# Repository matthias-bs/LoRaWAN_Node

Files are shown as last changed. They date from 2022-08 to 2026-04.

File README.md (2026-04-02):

# LoRaWAN_Node

Please refer to my [BresserWeatherSensorLW](https://github.com/matthias-bs/BresserWeatherSensorLW) project for an example application. The hardware has some options for a variety of other uses, however.

## TTN Node Board

### Schematic
Please refer to Fritzing or PDF file for most current version!

ttn_node-20220614-2_sch

### PCB
Please refer to Fritzing or PDF file for most current version!

**Note:**

Actually an antenna should not be placed next to circuitry or metal parts, but the decision was made to place the antenna inside the case to avoid leakage or corrosion problems. The concept works perfectly for me. 

ttn_node_v3_pcb

LoRaWAN_Node-1

LoRaWAN_Node-2

### Connectors/Wiring

#### Internal Wiring
```
                           (1)    Fuse
                      + o--------< F1 >-----< +
              BATT1                             U2 (Charger), "Batt"
                      - o-------------------< -
                                 (2)

                      + >-------------------< +
U2 (Charger), "Load"                            U1 (ESP32_Firebeetle)
                      - >-------------------< -
```
Wires (1) and (2) are only needed if the battery holder does not have PCB pins.

#### Connector Wiring
```
                                
                     Power  2 >------------------< +
     Solar Power In                                   2.1mm DC Jack (U2, Charger)
                       GND  1 >------------------< -

                       GND  1 >----------------< 1  GND
     OneWire Socket    VDD  2 >----------------< 2  3V3   LoRaWAN_Node, J2
                       DQ   3 >----------------< 3  DQ
```

ttn_node_wiring

LoRaWAN_Node-3

LoRaWAN_Node-4

### Assembly Options
1. Do not assemble R42, R43, R44 and R55.
2. Assemble C40, R40 and R41 for battery voltage measurement.
3. Assemble R1 if a one-wire sensor is to be used (and this sensor does not have an internal pull-up).
4. Assemble R2 and R3 for connection of I<sup>2</sup>C devices.
5. No pin header has to be assembled for the charger module. The apparently missing connections on the PCB drawing to the module can be ignored.

### Issues and Workarounds
1. The mounting holes are too small for the selected screws (special form; SHR Z B4,5x7,8)<sup>(1)</sup><br>(Fritzing limitation)<br>Workaround: Drilling with 4.5mm or a little filing.
2. The cutouts at the lower corners of the PCB have to be done manually.<br>(apparently Fritzing does not support PCB cutouts)
3. The footprint for the fuse F1 is too narrow.<br>As a workaround, F1 can be placed instead of connector J6 and a pin header at the actual F1 pads can be used to connect the fuse in series to the battery B+ wire. (see photo)
4. Connection from battery B+ to analog input voltage divider is missing.<br>Workaround: Add a wire from B+ to J5.7 (A3) (see photo - white wire)
5. Optionally: Drill a hole to strap the battery in the holder. (see photo)
6. Please see issue https://github.com/matthias-bs/LoRaWAN_Node/issues/1 regarding J5.1 (A0) usage

(1) The screws on the photo are different ones.

## Main Components
### MCU Board
[DFRobot FireBeetle ESP32 IoT Microcontroller](https://www.dfrobot.com/product-1590.html)

**Note 1:** Assemble R10 and R11 with 0 Ohms resistors (or solder joints...) if you want to monitor VB.

**Note 2:** The USB-serial-converter seems to be quite picky - use a short USB cable and lower bitrate when flashing!

### LoRa Radio Transceiver
[Adafruit RFM95W LoRa Radio Transceiver Breakout](https://www.adafruit.com/product/3072) - **868 MHz Version!**

**Note:** Don't use the transceiver without antenna!

### Antenna
[Delock LoRa 868 MHz Antenna SMA plug 3 dBi omnidirectional](https://www.delock.de/produkt/89769/merkmale.html)

## Solar Battery Charger
[Adafruit Universal USB / DC / Solar Lithium Ion/Polymer charger - bq24074](https://www.adafruit.com/product/4755)

**Note:** "Load Out" voltage can be different from battery voltage in certain conditions - see [Adafruit Universal USB / DC / Solar Lithium Ion/Polymer charger - bq24074 -- Overview](https://learn.adafruit.com/adafruit-bq24074-universal-usb-dc-solar-charger-breakout/overview).

## Solar Panel
[Waveshare Solar Panel (6V 5W)](https://www.waveshare.com/solar-panel-6v-5w.htm)

## Options

* [Adapter for DS3231 RTC Module](RTC_Adapter/RTC_Adapter.md)

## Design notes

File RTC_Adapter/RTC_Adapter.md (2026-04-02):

# Adapter for DS3231 RTC Module (for Raspberry Pi) to LoRaWAN_Node

This adapter allows to connect the [DS3231 RTC Module for Raspberry Pi](https://www.berrybase.de/en/ds3231-real-time-clock-module-for-raspberry-pi) to LoRaWAN_Node.

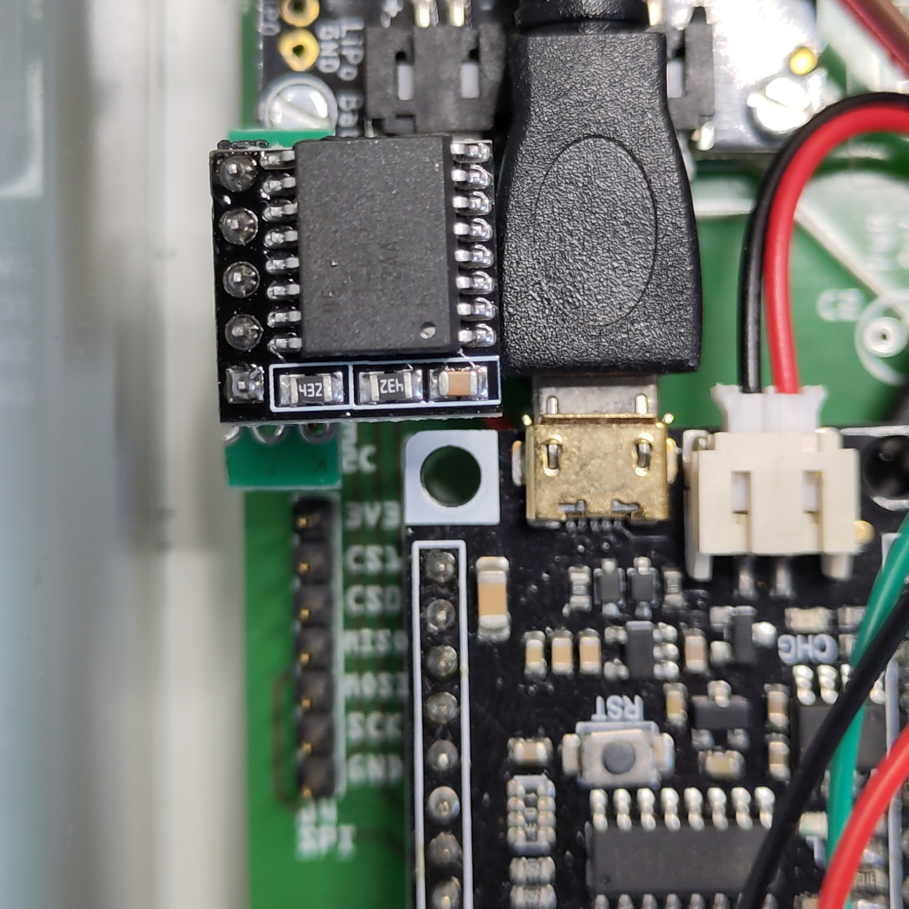
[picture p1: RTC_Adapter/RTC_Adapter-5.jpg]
Mounting Position

                                                                                                                                                                  
The RTC module is connected to the LoRaWAN_Node's connector J3 (I2C Bus).

**Wiring Scheme:**

```ascii
DS3231 Module                  
(Top View; IC)                 
 ┌─────────┐                   
 │ GND   5 ├─────┐ LoRaWAN Node (J3)
 │         │     │  ┌───────┐  
 │ NC    4 │  ┌──┼──┤ 4 3V3 │  
 │         │  │  │  │       │  
 │ SCL   3 ├──┼──┼──┤ 3 SCL │  
 │         │  │  │  │       │  
 │ SDA   2 ├──┼──┼──┤ 2 SDA │  
 │         │  │  │  │       │  
 │ 3V3   1 ├──┘  └──┤ 1 GND │  
 └─────────┘        └───────┘  

```

1. 4-Position Socket Header and Vias for SCL and SDA - Soldering

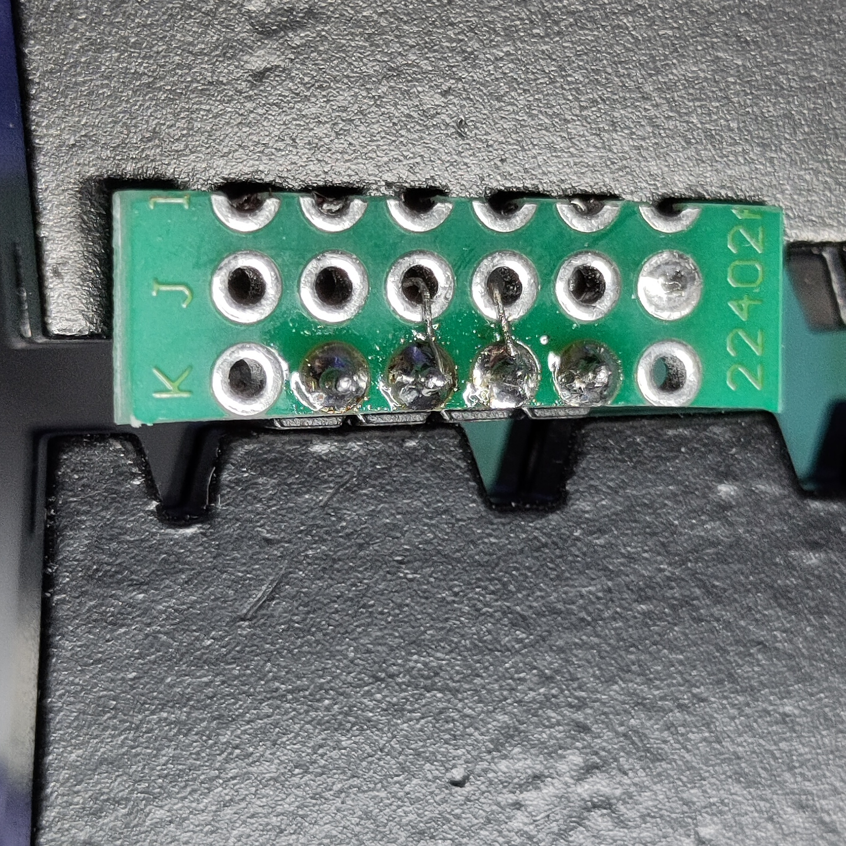
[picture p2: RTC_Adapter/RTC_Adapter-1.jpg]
4-Position Socket Header and Vias - Soldering
   

2. 4-Position Socket Header and Vias for SCL and SDA - Mounting Position

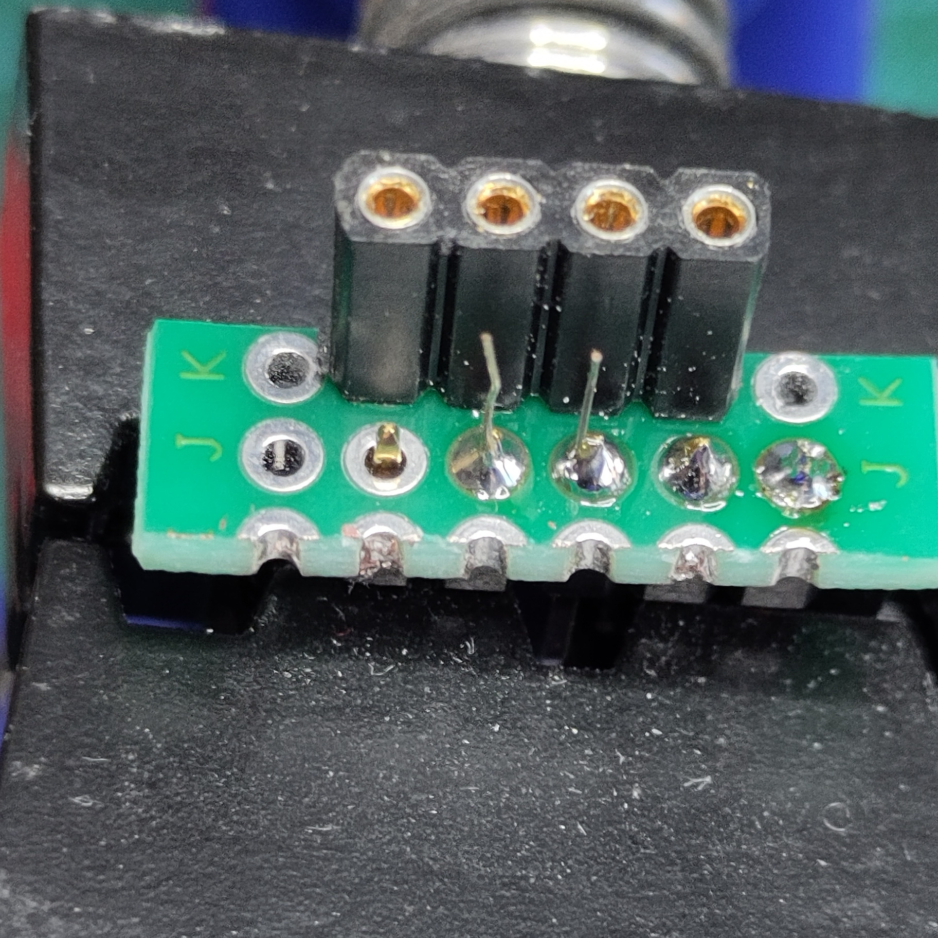
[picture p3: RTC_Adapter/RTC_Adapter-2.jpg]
4-Position Socket Header and Vias - Mounting Position
   

3. 5-Position Pin Header - Mounting Position

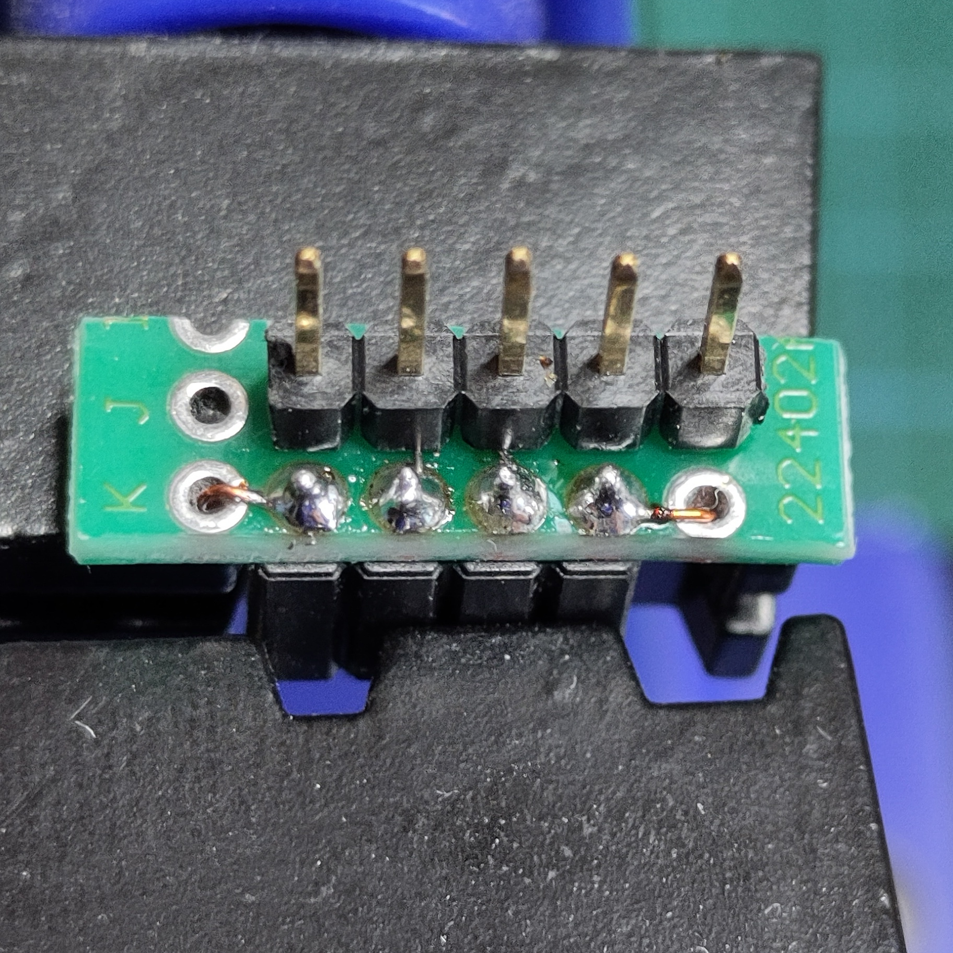
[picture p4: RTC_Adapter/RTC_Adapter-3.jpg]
5-Position Pin Header - Mounting Position
   

4. 5-Position Pin Header - 3V3 and GND Wiring

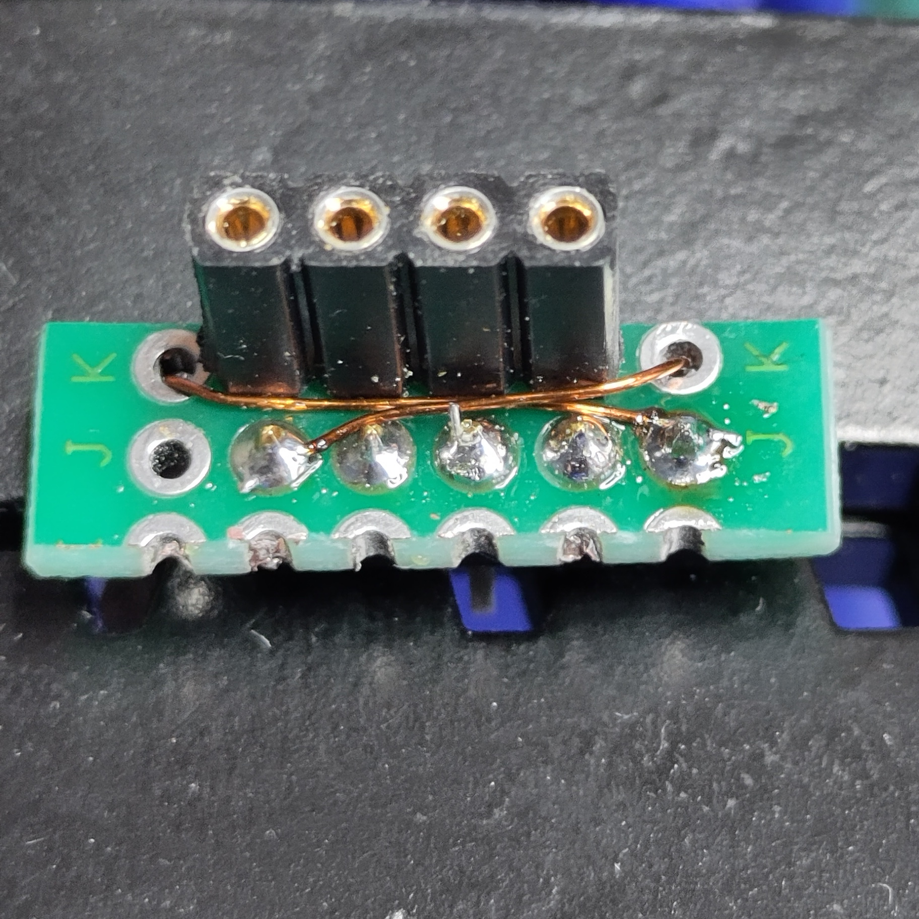
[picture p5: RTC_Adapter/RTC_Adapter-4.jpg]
5-Position Pin Header - 3V3 and GND Wiring


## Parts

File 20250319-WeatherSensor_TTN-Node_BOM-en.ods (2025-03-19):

Pos. | Quantity |  | Unit | Assembly | Part | Part No. | Link
 | min | max
1 | 1 | 1 | Pcs | Sensors | Bresser 5-in-1 Wetterstation |  | https://www.aldi-onlineshop.de/p/5-in-1-wetterstation-1008343/
2 | 1 | 1 | Pcs | Controller | Leiterplatte |  | https://aisler.net
3 | 1 | 1 | Pcs | Controller | FireBeetle ESP32 IOT Microcontroller | DFR0478 | https://www.komputer.de/zen/index.php?main_page=product_info&products_id=442
4 | 1 | 1 | Pcs | Radio Module | Adafruit RFM95W LoRa Radio Transceiver Breakout, 868 oder 915 Mhz | ADA3072 | https://www.berrybase.de/sensoren-module/funk-wlan-bluetooth/adafruit-rfm95w-lora-radio-transceiver-breakout-868-oder-915-mhz
5 | 1 | 1 | Pcs | Radio Module | SMA Einbaubuchse SMA Buchse Printmontage, löten, 10mm M6 | n.a. | https://www.ebay.de/itm/185362207632
6 | 1 | 1 | Pcs | Radio Module | LoRa 868 MHz Antenne SMA 3 dBi omnidirektional, Kippgelenk | DELOCK 89769 | https://www.reichelt.de/lora-868-mhz-antenne-sma-3-dbi-omnidirektional-kippgelenk-delock-89769-p236860.html
7 | 1 | 1 | Pcs | Case/Assembly/Mounting | Industriegehäuse, 200 x 120 x 75 mm, IP66, lichtgrau | 5U220100 | https://www.reichelt.de/industriegehaeuse-200-x-120-x-75-mm-ip66-lichtgrau-5u220100-p324347.html
8 | 1 | 1 | Pcs | Case/Assembly/Mounting | Rohrschelle Hydraulikrohr 42mm, Einzelrohrschelle | n.a. | https://www.ebay.de/itm/202800309155
9 | 0,2 | 0,2 |  | Case/Assembly/Mounting | Glattblech 500 x 250 mm, Stärke: 0,8 mm, Aluminium, Blank
10 | 0,5 | 0,5 | m | Case/Assembly/Mounting | Alu-Profil, Flachstange 1000mm x 25mm
11 | 0,25 | 0,25 | m | Case/Assembly/Mounting | Alu-Profil, U-Profil 1000mm x 15,9mm
12 | 4 | 4 | Pcs | Case/Assembly/Mounting | Schraube M4x30, VZ
13 | 2 | 2 | Pcs | Case/Assembly/Mounting | Schraube M4x10, V2A
14 | 2 | 2 | Pcs | Case/Assembly/Mounting | Mutter M4, V2A
15 | 4 | 4 | Pcs | Case/Assembly/Mounting | Distanzhülse, Metall, 6-Kant, M4, 20mm | DI4 20MM | https://www.reichelt.de/distanzhuelsen-metall-6-kant-m4-20mm-di4-20mm-p44776.html
16 | 2 | 2 | Pcs | Case/Assembly/Mounting | Schlauchschelle 32-50mm, V2A
17 | 4 | 4 | Pcs | Case/Assembly/Mounting | Distanzhülsen ø2,2x4 (ø3,5x5)
18 | 4 | 4 | Pcs | Case/Assembly/Mounting | Schrauben M2x10
19 | 4 | 4 | Pcs | Case/Assembly/Mounting | Mutter M2
20 | 4 | 4 | Pcs | Case/Assembly/Mounting | Schraube Bopla SHR Z B4,5x7,8 (SD = 4,5 / ND = 4,0 / KD = 7,5; alternativ: #8 - 32 UNC (gekürzt)) | 59006101 | https://www.bopla.de/gehaeusetechnik/product/kabelverschraubungen-allgemeines-zubehoer/schrauben-und-bolzen/shr-z-b45x78.html
21 | 0 | 1 | Pcs | Sensors | Leiterplatten-Abstandshalter
22 | 0 | 1 | Pcs | Sensors | Lumberg Quicklock-Einbaukupplung - Größe 12, 3 pol (Temperatursensor) | LUM 0270-03 | https://www.reichelt.de/quicklock-einbaukupplung-groesse-12-3-pol-lum-0270-03-p239488.html
23 | 0 | 1 | Pcs | Power Supply | Lumberg Quicklock Gr. 12 Stecker 3pol. | LUM 0250-03 | https://www.reichelt.de/quicklock-stecker-groesse-12-3-pol-lum-0250-03-p239474.html
24 | 1 | 1 | Pcs | Power Supply | Lumberg Quicklock-Einbaukupplung - Größe 12, 2 pol (Power) | LUM 0270-02 | https://www.reichelt.de/quicklock-einbaukupplung-groesse-12-2-pol-lum-0270-02-p239487.html
25 | 1 | 1 | Pcs | Power Supply | Lumberg Quicklock Gr. 12 Stecker 2pol. | LUM 0250-02 | https://www.reichelt.de/quicklock-stecker-groesse-12-2-pol-lum-0250-02-p239473.html
26 | 1 | 1 | Pcs | Power Supply | Solarpanel, 6 V / 5 W | DEBO SOLAR 5W | https://www.reichelt.de/entwicklerboards-solarpanel-5-w-debo-solar-5w-p266039.html
27 | 1 | 1 | Pcs | Power Supply | Adafruit Universal USB / DC / Solar Lithium Ion/Polymer Ladegerät | ADA4755 | https://www.berrybase.de/adafruit-universal-usb/dc/solar-lithium-ion/polymer-ladeger-228-t
28 | 1 | 1 | Pcs | Power Supply | Industriezelle, 18650, 3,6 V, 3180 mAh, ungeschützt, 1er-Pack | PAN 18650 BD | https://www.reichelt.de/industriezelle-18650-3-6-v-3180-mah-ungeschuetzt-1er-pack-pan-18650-bd-p317977.html
29 | 1 | 1 | Pcs | Power Supply | Batteriehalter für 1x 18650 | HALTER MPD5 | https://www.reichelt.de/batteriehalter-fuer-1x-18650-halter-mpd5-p213339.html
30 | 2 | 3 | Pcs | Power Supply | Kabel LiPo kompatibel mit 2 Pin JST PH 2.0mm Steckverbinder, AWG26, 20cm | AK-PH20-LP2P | https://www.berrybase.de/kabel-lipo-kompatibel-mit-2-pin-jst-ph-2.0mm-steckverbinder-awg26-20cm
31 | 0 | 1 | Pcs | Power Supply | NTC-Widerstand, 0,5 W, 10 kOhm | NTC-0,2 10K | https://www.reichelt.de/ntc-widerstand-0-5-w-10-kohm-ntc-0-2-10k-p13553.html
32 | 1 | 2 | Pcs | Controller | Elko radial, 10 µF, 50 V, 105°, Low ESR, 5 x 11 mm, RM 2 | FR-A 10U 50 | https://www.reichelt.de/elko-radial-10-f-50-v-105-low-esr-5-x-11-mm-rm-2-fr-a-10u-50-p200268.html
33 | 0 | 1 | Pcs | Power Supply | Micro-USB Einbaubuchse Wasserdicht; Note: D=15 mm | n.a. | https://smile.amazon.de/dp/B07ZCZ8NL1
33a | 0 | 1 | Pcs | Power Supply | Micro-USB Einbaubuchse Wasserdicht; Note: D=12 mm | ADA6068 | https://www.adafruit.com/product/6068
34 | 0 | 1 | Pcs | Sensors | Xiaomi Mi Temperatur-und Feuchtigkeitsmonitor 2, Weiß, 43 mm | n.a. | https://www.amazon.de/gp/product/B08C7KVDJW/
35 | 0 | 1 | Pcs | Sensors | Entwicklerboards - Temperatursensor bis 125 °C, DS18B20 | DEBO LK-TEMP | https://www.reichelt.de/entwicklerboards-temperatursensor-bis-125-c-ds18b20-debo-lk-temp-p299375.html
36 | 0 | 6 | m | Sensors | Steuerleitung 4x0,14mm², ungeschirmt, 10m-Ring | LIYY 414-10 | https://www.reichelt.de/steuerleitung-4x0-14mm-ungeschirmt-10m-ring-liyy-414-10-p10365.html

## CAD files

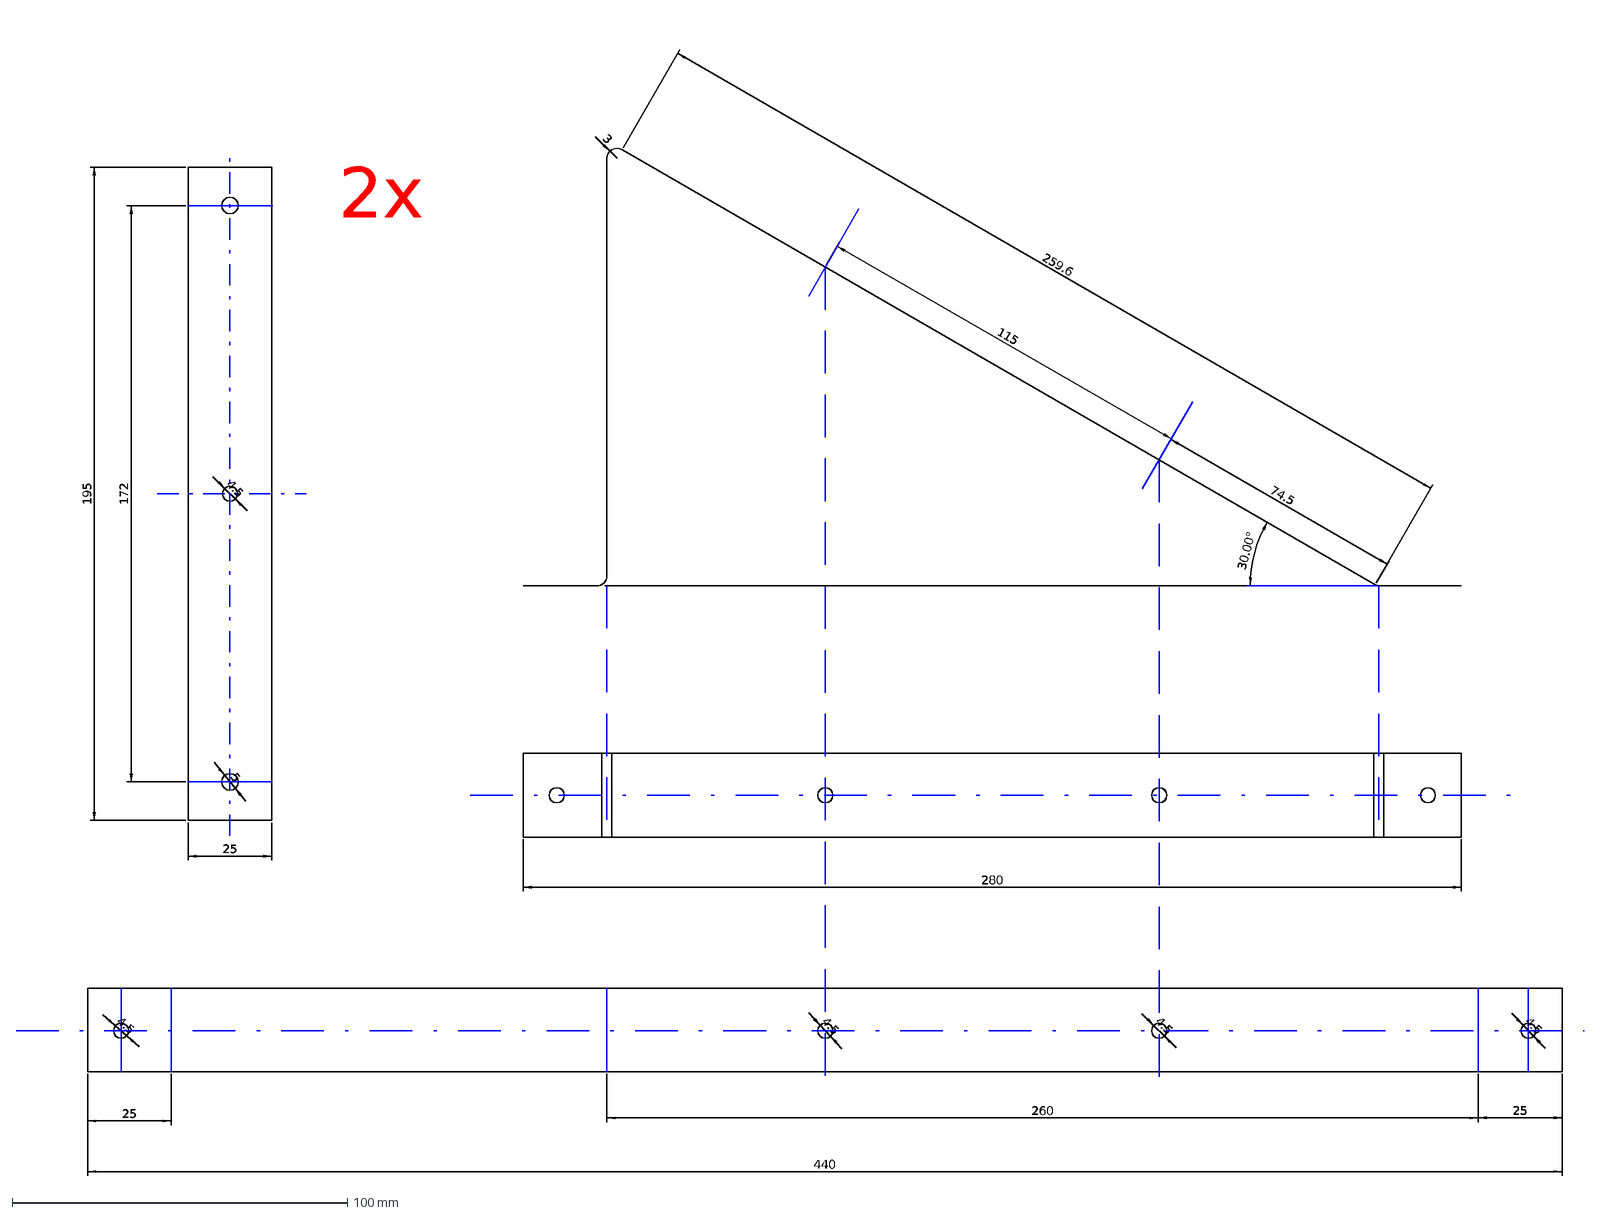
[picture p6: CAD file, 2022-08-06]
mount_debo_solar_5w_20220519.dxf
115
259.6
74.5
280
3
440
260
25
4.5
30.00°
5
195
172
2x

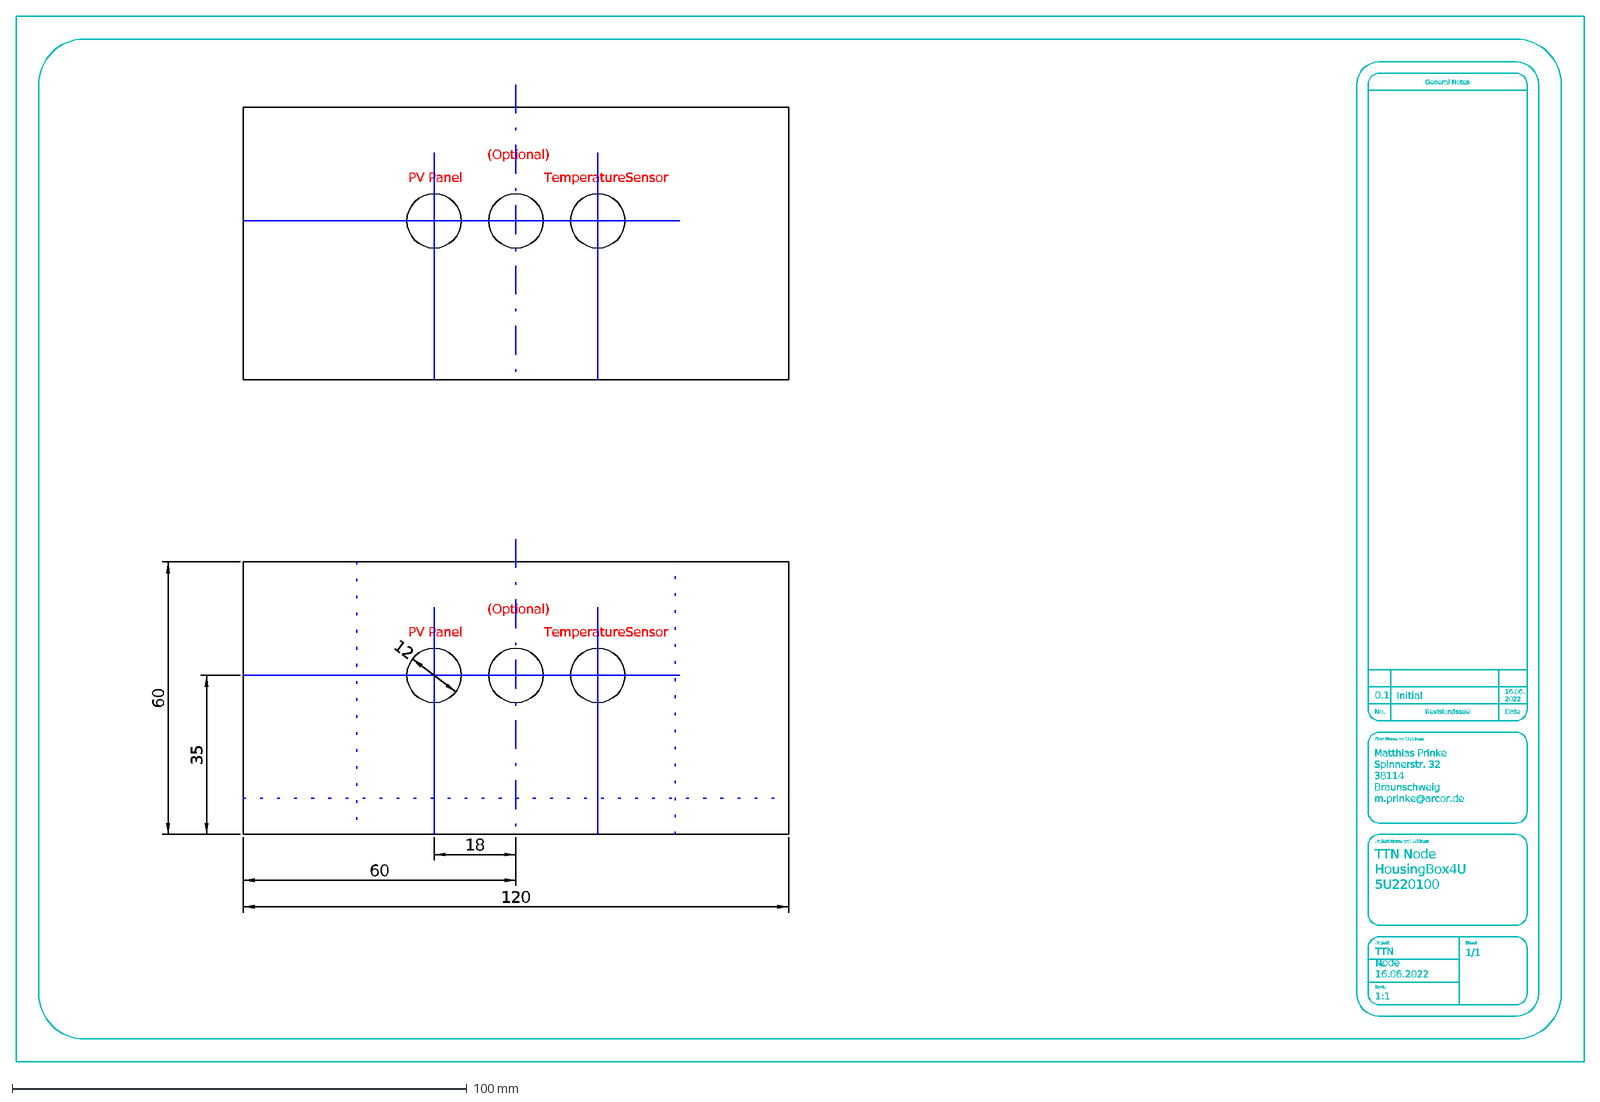
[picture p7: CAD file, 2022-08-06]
ttn_node_panels_rev01.dxf
60
120
TemperatureSensor
(Optional)
18
PV Panel
35
Scale
Project
Date
Sheet
Revision/Issue
Project Name and Address
Firm Name and Address
No.
General Notes
Matthias Prinke Spinnerstr. 32 38114 Braunschweig m.prinke@arcor.de
1:1
0.1
Initial
1/1
TTN Node Housing Box4U 5U220100
16.06.2022
TTN Node
16.06. 2022
12

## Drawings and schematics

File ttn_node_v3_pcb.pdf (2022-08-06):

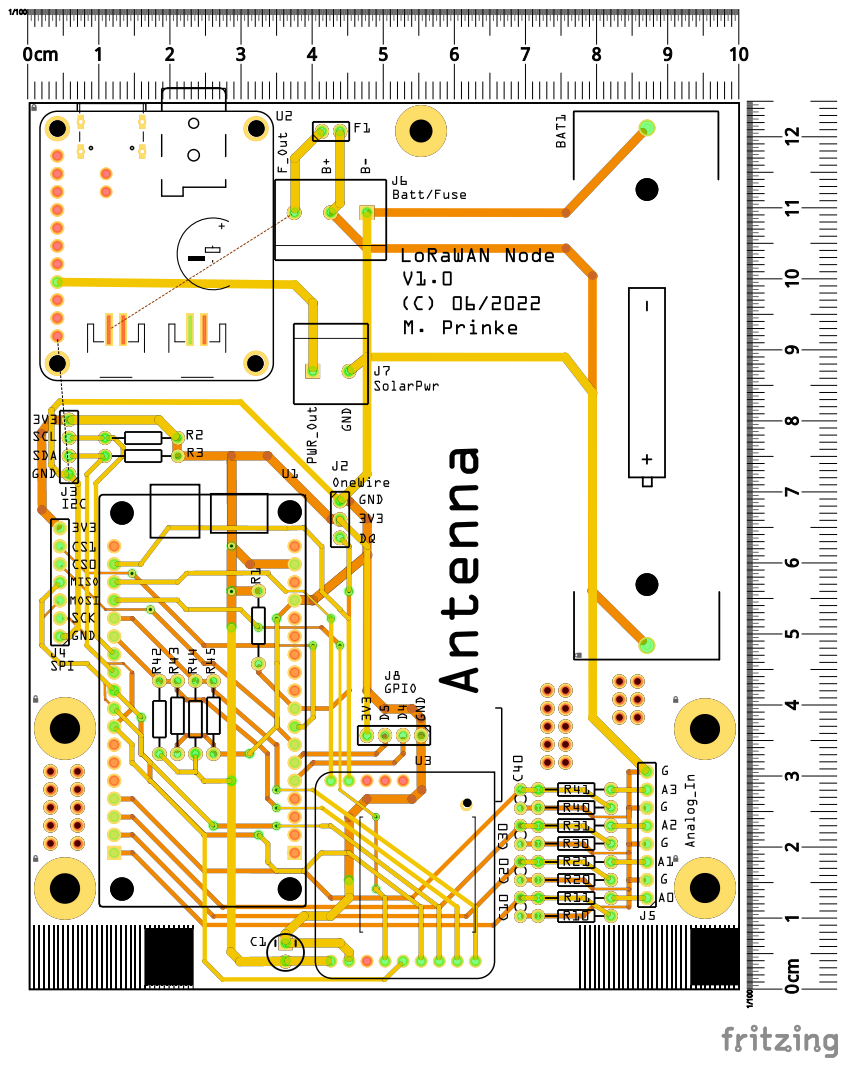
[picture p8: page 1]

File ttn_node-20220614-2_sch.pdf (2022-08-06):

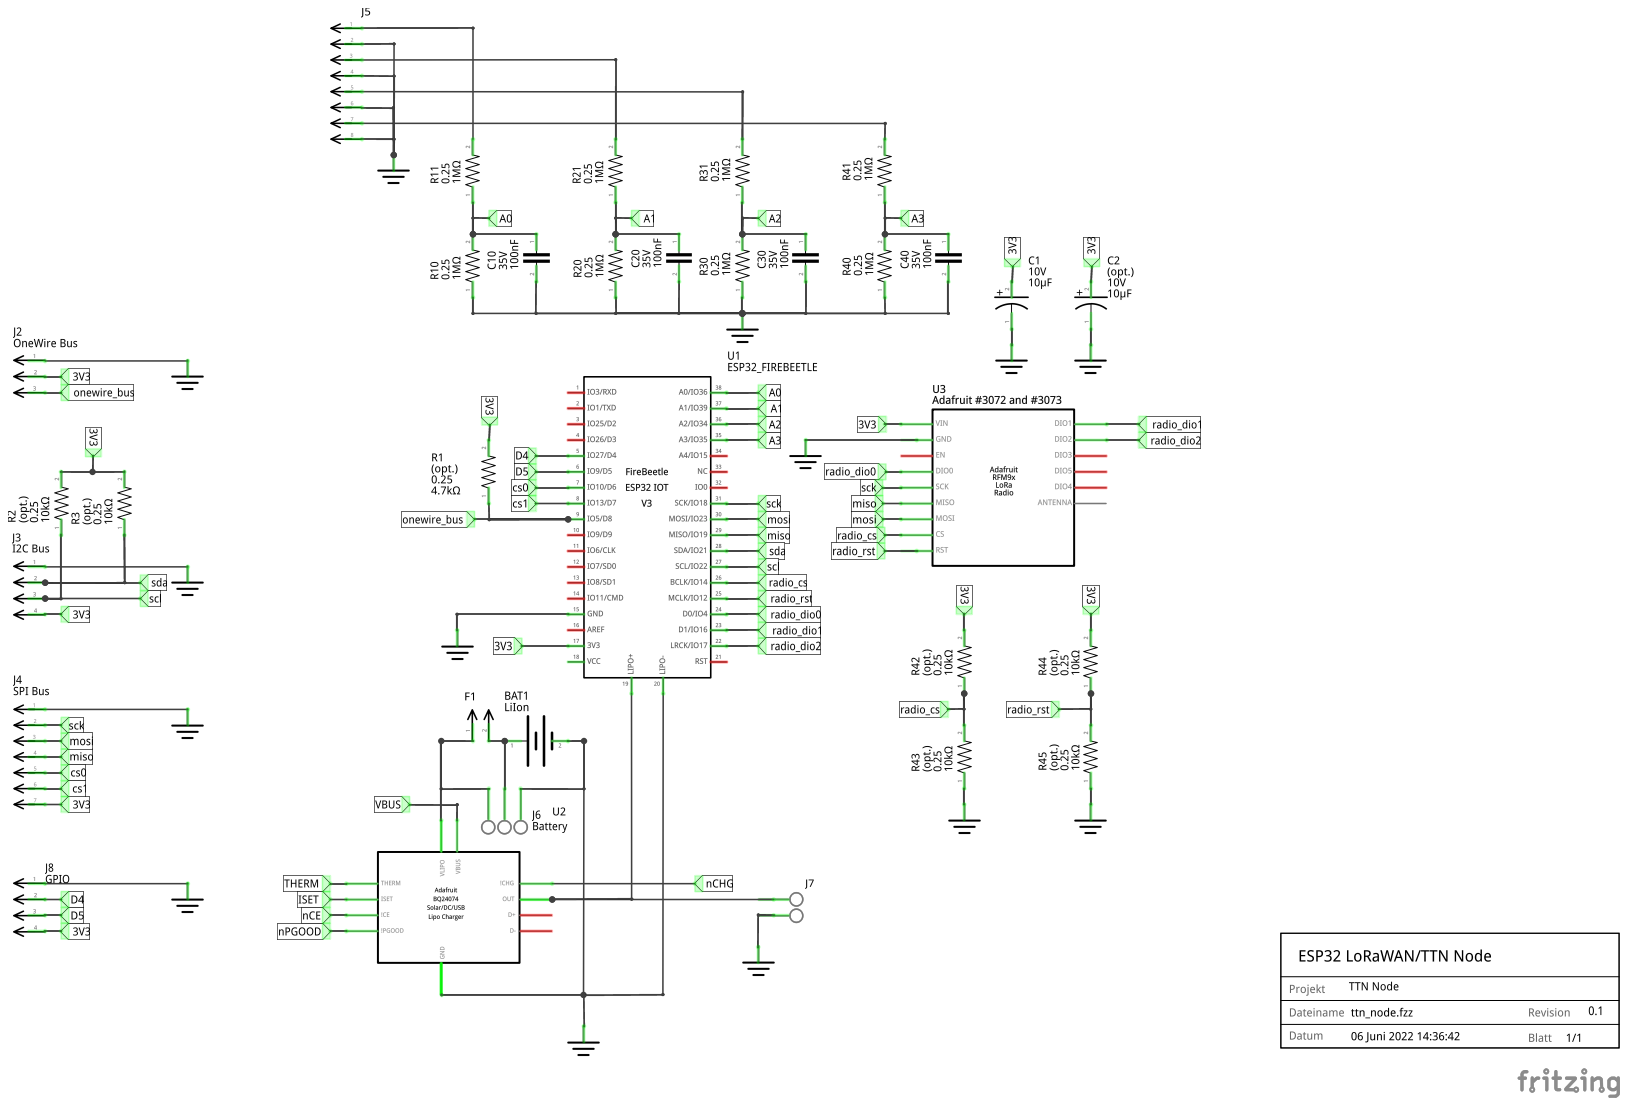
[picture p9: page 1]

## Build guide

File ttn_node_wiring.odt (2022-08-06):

TTN Node – Wiring

19.05.2022

Sockets (Lumberg Quicklock 12) | Pin | Signal | Wire external | Wire internal
| 1 | GND | br (sw)
| 2 | VDD | ws (rt)
| 3 | DQ | ge (ge)
| 1 | GND | sw | sw
| 2 | Power | rt | rt

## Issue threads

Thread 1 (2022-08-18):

Pin A0 mapping

matthias-bs, 2022-08-18:
A0 can be connected to VB on the FireBeetle ESP32 board (if R10 and R11 are assembled), but it is also connected to the external input J5.1 via a voltage divider.
To be able to use both ADC input sources independently, the analog inputs of the LoRaWAN_Node PCB should be changed from A0...3 to A1...4.

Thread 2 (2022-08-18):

F1 has wrong footprint

matthias-bs, 2022-08-18:
The footprint for the fuse F1 is too narrow.
As a workaround, F1 can be placed instead of connector J6 and a pin header at the actual F1 pads can be used to connect the fuse in series to the battery B+ wire. (see photo)

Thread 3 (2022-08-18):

Connection from B+ to analog input for battery voltage measurement missing

matthias-bs, 2022-08-18:
Connection from battery B+ to analog input voltage divider is missing.

Workaround: Add a wire from B+ to J5.7 (A3) (see photo - white wire)

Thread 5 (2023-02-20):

Add Sensor Power Switch (optional)

matthias-bs, 2023-02-20:
Add sensor power switch circuit, e.g. for multiple [A02YYUW / DFRobot SEN0311 Ultrasonic Distance Sensors](https://wiki.dfrobot.com/_A02YYUW_Waterproof_Ultrasonic_Sensor_SKU_SEN0311).

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

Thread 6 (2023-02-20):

Add ESD protection

matthias-bs, 2023-02-20:
Add TVS diodes for enhanced ESD protection of inputs connected to external sensors (with long wires), e.g. OneWire or UART.
